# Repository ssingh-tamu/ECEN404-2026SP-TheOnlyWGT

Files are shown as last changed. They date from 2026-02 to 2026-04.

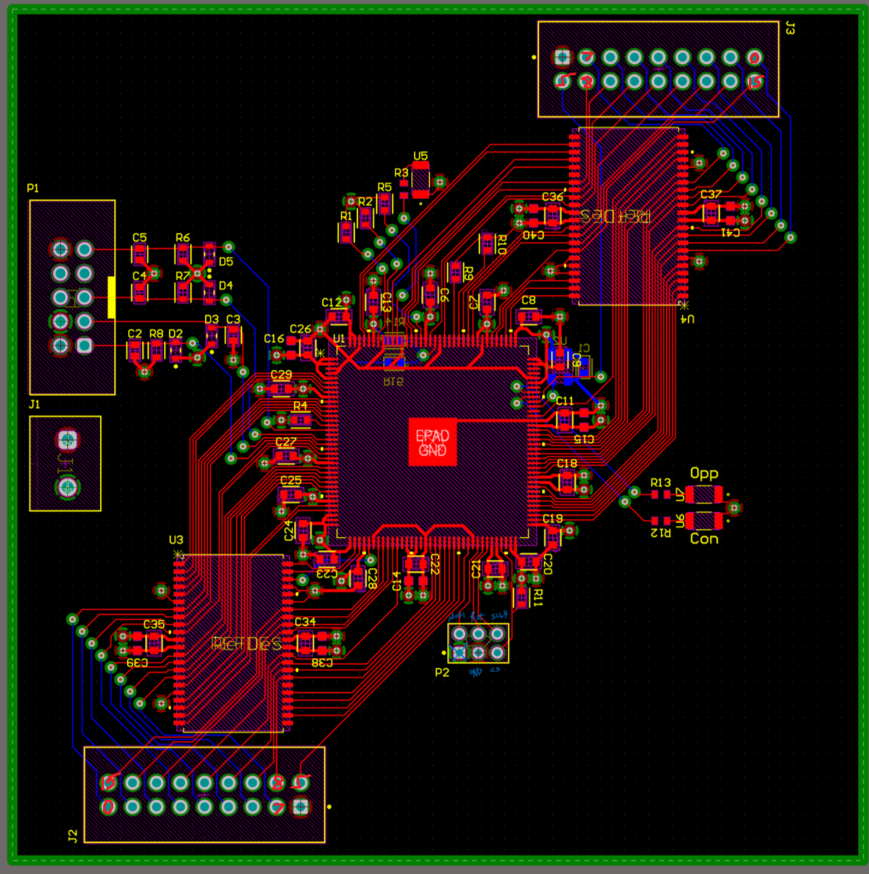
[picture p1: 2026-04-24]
FPGA/fpga pcb pinout.png

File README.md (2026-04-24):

# The-Only-WGT-FinalGIT
ECEN CAPSTONE: 2 Channel Arbritrary Waveform Generating team #25 at TAMU. 

Sponsor:
Dr. John Lusher (johnlusher)

Contents:
Project data, reports, presentations, code, measurements, plans, and results. 

How to use code:
Download code as a zip file and run locally on personal device
Mobile App: Use VScode or other compatible IDE and Arduino IDE to start BLE search

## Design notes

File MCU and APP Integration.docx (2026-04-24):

STANDARD FUNCTIONS- Completed

- BLE peripheral name: ESP32-JOE
- Service UUID (Nordic UART / NUS): 6e400001-b5a3-f393-e0a9-e50e24dcca9e
- App steps (connect):
  - Scan for a BLE device named ESP32-JOE (or advertising the NUS service UUID above)
  - Connect
  - Discover services/characteristics
  - Find these characteristics under the NUS service:
    - RX (WRITE to ESP32): 6e400002-b5a3-f393-e0a9-e50e24dcca9e
    - TX (NOTIFY from ESP32): 6e400003-b5a3-f393-e0a9-e50e24dcca9e

To send a Standard Wave command (STD):

  - Do a GATT Write to the RX characteristic (6e400002-...)
  - Payload is 17 bytes total, little-endian for multi-byte numbers:
- STD packet format (17 bytes):
  - Byte 0: 'S' (0x53)
  - Byte 1: shape (u8)
    - 0 = sine
    - 1 = square
    - 2 = triangle
    - 3 = sinc
  - Bytes 2–5: freq_mHz (u32, little-endian)
    - freq in milli-Hz = Hz * 1000
  - Bytes 6–9: amp_mVpp (u32, little-endian)
    - amplitude in mV peak-to-peak = Vpp * 1000
  - Bytes 10–13: offset_mV (s32, little-endian)
    - DC offset in mV = V * 1000 (signed)
  - Bytes 14–15: phase_deg (s16, little-endian)
    - phase in degrees (signed)
  - Byte 16: channel (u8)
    - 0 = channel A
    - 1 = channel B
- Example values (so they can sanity check):
  - 1 kHz → freq_mHz = 1,000,000
  - 2.0 Vpp → amp_mVpp = 2000
  - +0.5 V offset → offset_mV = 500
  - phase 90° → phase_deg = 90
  - channel A → channel = 0

ARBITRARY FUNCTIONS- SCRAPED

“Interpolation” of points to reduce transmission time.

Here’s a quick write-up you can paste to the app person. It’s written like a mini “protocol spec”.

## ESP32 BLE Connection + Arbitrary Waveform Upload (Protocol)

### 1) BLE service + characteristics

The ESP32 advertises as ESP32-JOE and uses the Nordic UART Service (NUS).

Discover:

- Service UUID: 6e400001-b5a3-f393-e0a9-e50e24dcca9e
- RX (Write) characteristic UUID: 6e400002-b5a3-f393-e0a9-e50e24dcca9e ← app writes packets here
- TX (Notify) characteristic UUID: 6e400003-b5a3-f393-e0a9-e50e24dcca9e (optional; not required for upload)

Connection steps:

1. Scan for ESP32-JOE
2. Connect
3. Discover NUS service
4. Write all commands to the RX characteristic

### 2) Arbitrary waveform upload overview

Arbitrary waveform upload is 3 phases:

1. META: start upload + set channel + set frequency
2. DATA: stream 16-bit samples in chunks(Edit this so app sends all 64k points)
3. END: commit (only succeeds if exactly 1024 samples received)

Total samples required: 1024 (exactly)

All multi-byte integers are Little Endian (LE).

### 3) Packets

#### A) META packet (start new ARB upload)

Format:
'A' + channel(1 byte) + freq_mHz(u32 LE)

- Byte 0: ASCII 'A' = 0x41
- Byte 1: channel:
  - 0 = Channel A
  - 1 = Channel B
- Bytes 2–5: freq_mHz as uint32 LE
  - Frequency is in milli-Hz (Hz * 1000)

Example: Channel A, 1000 Hz
freq_mHz = 1,000,000
Payload: [0x41, 0x00, 0x40, 0x42, 0x0F, 0x00]

Sending META resets/clears the ARB buffer on the MCU.

#### B) DATA packet (send samples)

Format:
'D' + count(u16 LE) + samples[count] (each sample u16 LE)

- Byte 0: ASCII 'D' = 0x44
- Bytes 1–2: count = number of samples in this packet (uint16 LE)
- Remaining bytes: count samples, each a uint16 LE DAC code

Repeat DATA packets until the MCU has received 1024 total samples.

#### C) END packet (commit)

Format:
'Z'

- Single byte: ASCII 'Z' = 0x5A

Commit rules:

- MCU only commits if META was received and exactly 1024 samples have been received total.
- If not 1024, it rejects the upload.

### 4) Sample encoding (what the 16-bit numbers mean)

Each sample is a raw uint16 DAC code: 0 … 65535.

If your app generates values in volts and the hardware range is ±5 V, map like this (clamp to range):

- code = round((v + 5.0) * (65535 / 10.0))
- v = −5.0 → 0
- v = +5.0 → 65535

(If the app already generates 0..65535 codes, send directly.)

### 5) BLE payload sizing / chunk size

DATA packet size is: 3 + 2*count bytes.

Pick count so the whole DATA packet fits in the BLE write payload (depends on MTU).

- If MTU is default (~20 payload bytes), max count ≈ 8 samples per packet.
- If MTU is negotiated larger (recommended), you can send bigger chunks (ex: 60 samples → 123 bytes).

Recommendation:

- Request a higher MTU if supported and stream DATA packets sequentially (write-with-response preferred for reliability).

### 6) Minimal send sequence summary

1. Connect to BLE device ESP32-JOE
2. Write META: 'A' + channel + freq_mHz(LE u32)
3. Send DATA packets until 1024 samples total are sent
4. Write END: 'Z'

# Arbitrary Waveform Upload

### BLE Packet Flow – Explained (with Real Example)

This document explains why multiple BLE packets are sent when uploading an arbitrary waveform and what each packet means on the MCU side.

## Overview

When sending an arbitrary waveform to the MCU:

- The waveform always contains exactly 1024 samples
- Samples are sent in chunks to fit BLE packet size limits
- The upload happens in three phases:
  1. META (start upload)
  2. DATA (send waveform samples)
  3. END (commit waveform)

## Packet Types Summary

Packet | Byte | Purpose
META | 'A' (0x41) | Start ARB upload, set channel & frequency
DATA | 'D' (0x44) | Send waveform samples
END | 'Z' (0x5A) | Commit waveform (only if 1024 samples received)

Any packet that is not the standard 17-byte AWG packet ('S') is logged by the MCU as NON-STANDARD PACKET — this is expected.

## Real Example From MCU Log

RX write [123 bytes]

RX write [11 bytes]

RX write [1 bytes]

This is correct and expected behavior.

## 1️⃣ First Packet – DATA (123 bytes)

44 3c 00 ...

### What it means:

- 0x44 → 'D' = DATA packet
- 0x3c 0x00 → 60 samples (little-endian)
- Remaining bytes → 60 × 2 = 120 bytes of sample data

### Why 123 bytes total?

1 byte → 'D'

2 bytes → sample count

120 bytes → waveform samples

123 bytes total

✔ This is the main waveform chunk
✔ Size chosen to fit BLE MTU safely

## 2️⃣ Second Packet – DATA (11 bytes)

44 04 00 45 67 45 67 45 67 45 67

### What it means:

- 'D' → DATA packet
- 0x04 0x00 → 4 samples
- 4 × 2 = 8 bytes of data

### Why only 4 samples?

1024 total samples

− 60 × 17 packets = 1020 samples

4 samples remaining

✔ This packet sends the final remainder

## 3️⃣ Final Packet – END (1 byte)

5a

### What it means:

- 0x5A → 'Z' = END / COMMIT packet

### What the MCU does here:

- Checks:
  - META packet was received
  - Exactly 1024 samples were received
- If valid → waveform is committed
- If not → upload is rejected

✔ This byte is always exactly 0x5A
✔ No payload, no length field

## Why the MCU Prints “NON-STANDARD PACKET”

The MCU firmware distinguishes between:

- Standard AWG packet ('S', 17 bytes)
- Arbitrary waveform packets ('A', 'D', 'Z')

So the log message:

>>> NON-STANDARD PACKET

Simply means:

“This is not the 17-byte AWG packet”

It does not indicate an error.

## Final Packet Flow Summary

Order | Packet | Size | Purpose
1 | 'A' | 6 bytes | Start upload (META)
2 | 'D' | 123 bytes | 60 samples
3 | 'D' | 123 bytes | 60 samples
… | 'D' | 123 bytes | More chunks
n | 'D' | 11 bytes | Final 4 samples
last | 'Z' | 1 byte | Commit waveform

## Key Takeaways

- Multiple DATA packets are required
- Different packet sizes are normal
- The final 0x5A byte is mandatory

ARBITRARY FUNCTIONS- App sends full 64k Packet: (MCU Getting larger memory chip) PSRAM 8MG useable

- Expect transmission time to be longer

## ESP32 BLE Connection + Arbitrary Waveform Upload (Protocol)

### 1) BLE service + characteristics

The ESP32 advertises as ESP32-JOE and uses the Nordic UART Service (NUS).

Discover:

- Service UUID: 6e400001-b5a3-f393-e0a9-e50e24dcca9e
- RX (Write) characteristic UUID: 6e400002-b5a3-f393-e0a9-e50e24dcca9e ← app writes packets here
- TX (Notify) characteristic UUID: 6e400003-b5a3-f393-e0a9-e50e24dcca9e (optional; not required for upload)

Connection steps:

5. Scan for ESP32-JOE
6. Connect
7. Discover NUS service
8. Write all commands to the RX characteristic

### 2) Arbitrary waveform upload overview

Arbitrary waveform upload is 3 phases:

4. META: start upload + set channel + set frequency
5. DATA: stream 16-bit samples in chunks(Edit this so app sends all 64k points)
6. END: commit (only succeeds if exactly 1024 samples received)

Total samples required: 1024 (exactly)

All multi-byte integers are Little Endian (LE).

### 3) Packets

#### A) META packet (start new ARB upload)

Format:
'A' + channel(1 byte) + freq_mHz(u32 LE)

- Byte 0: ASCII 'A' = 0x41
- Byte 1: channel:
  - 0 = Channel A
  - 1 = Channel B
- Bytes 2–5: freq_mHz as uint32 LE
  - Frequency is in milli-Hz (Hz * 1000)

Example: Channel A, 1000 Hz
freq_mHz = 1,000,000
Payload: [0x41, 0x00, 0x40, 0x42, 0x0F, 0x00]

Sending META resets/clears the ARB buffer on the MCU.

#### B) DATA packet (send samples)

Format:
'D' + count(u16 LE) + samples[count] (each sample u16 LE)

- Byte 0: ASCII 'D' = 0x44
- Bytes 1–2: count = number of samples in this packet (uint16 LE)
- Remaining bytes: count samples, each a uint16 LE DAC code

Repeat DATA packets until the MCU has received 1024 total samples.

#### C) END packet (commit)

Format:
'Z'

- Single byte: ASCII 'Z' = 0x5A

Commit rules:

- MCU only commits if META was received and exactly 1024 samples have been received total.
- If not 1024, it rejects the upload.

### 4) Sample encoding (what the 16-bit numbers mean)

Each sample is a raw uint16 DAC code: 0 … 65535.

If your app generates values in volts and the hardware range is ±5 V, map like this (clamp to range):

- code = round((v + 5.0) * (65535 / 10.0))
- v = −5.0 → 0
- v = +5.0 → 65535

(If the app already generates 0..65535 codes, send directly.)

### 5) BLE payload sizing / chunk size

DATA packet size is: 3 + 2*count bytes.

Pick count so the whole DATA packet fits in the BLE write payload (depends on MTU).

- If MTU is default (~20 payload bytes), max count ≈ 8 samples per packet.
- If MTU is negotiated larger (recommended), you can send bigger chunks (ex: 60 samples → 123 bytes).

Recommendation:

- Request a higher MTU if supported and stream DATA packets sequentially (write-with-response preferred for reliability).

### 6) Minimal send sequence summary

5. Connect to BLE device ESP32-JOE
6. Write META: 'A' + channel + freq_mHz(LE u32)
7. Send DATA packets until 1024 samples total are sent
8. Write END: 'Z'

MCU should…

Receive META 'A' with 10 bytes:

- [0]='A'
- [1]=channel
- [2..5]=freqMilliHz (uint32 LE)
- [6..9]=totalSamples (uint32 LE) → 32768

Receive many 'D' packets containing:

- 'D', count (uint16 LE), then count uint16 DAC samples

Stop on 0x5A

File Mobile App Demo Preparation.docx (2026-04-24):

## Mobile App

### 1. Purpose

- The mobile app provides a simple, intuitive way to connect to the AWG and create, edit, and transmit user-defined waveforms.
- Built in Flutter for cross-platform support on iOS, Android, and PC.
- Main goal: give users an easy way to control waveform generation from a mobile device.

### 2. Design Requirements

- Sponsor requirements from the FSR contract:
  - Define offset, frequency, amplitude, waveform type, and channel
  - Maintain a reliable and stable BLE connection
  - Prioritize simplicity, ease of use, adjustability, and include user-safegaurds
- Built-in safeguards:
  - Prevents drawing invalid arbitrary waveforms such as intersecting values, backward traces, or values outside the amplitude range
  - Prevents entering frequency, VPP, or offset values outside allowed limits
  - Detects BLE disconnects and prompts the user to reconnect
  - Only searches for ESP32 BLE devices, making connection faster and clearer

### 3. Connection Screen

- This is the first screen users see.
- The app scans only for ESP32 BLE devices and displays their names for easy selection.
- Users can quickly connect to the AWG through BLE.
- If the connection is lost, the app alerts the user and prompts reconnection.

How it works

- BLE communication is handled through RX/TX between the app and the ESP32.
- This creates a simple wireless link between the mobile device and the AWG controller.

### 4. Standard Waveform Screen

- This screen functions like a traditional signal generator interface.
- Users can configure:
  - Frequency
  - Amplitude
  - Offset
  - Waveform type
  - Channel

How it works

- The app sends a parameterized string in a predefined format to the MCU.
- The MCU uses those parameters to select and generate standard waveforms from stored LUTs.

### 5. Drawable Arbitrary Waveform Screen

- This screen allows users to draw their own custom waveform on a canvas.
- The interface is designed to keep the drawing valid and within system limits.
- Users cannot draw non-functions or values outside the allowed amplitude range.

### 6. Editing Screen

- After drawing, users can refine the waveform before sending it.
- Users can apply edits such as:
  - Frequency
  - Channel
  - Offset
- This gives more control before transmitting the final waveform.

How it works

- The drawn waveform is converted into 64k discrete values.
- Those values are sent to the MCU along with the selected frequency, channel, and offset settings.
- The MCU then generates a unique LUT for that arbitrary waveform.

Enclosure

1. Purpose

- The enclosure houses and protects the system components while keeping the design compact, lightweight, and easy to service.
- It was designed to support the PCB securely while still allowing access for adjustments and future upgrades.

### 2. Design Requirements

- Required weight: less than 5.5 lbs
  - Final weight: 501 grams without the lid
- Required footprint: less than 12 x 8 x 10 inches
  - Final dimensions with lid: 8 x 8 x 5 inches

### 3. Structural Features

- The enclosure is self-supporting
- Uses Velcro for easy PCB removal and reinstallation
- Includes two open rail slots for interior PCB adjustability
- Extra interior space allows for:
  - wire routing
  - component adjustments
  - future upgrades if needed

### 4. Manufacturing and Material Choices

- The box was 3D printed in PLA and CADed using SOLIDWORKS
- Reduced interior infill
  - minimize weight
  - reduce material cost
  - maintain sufficient structural support

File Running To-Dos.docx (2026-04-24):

To Dos:

- ~~Measure all subsystems PCBs~~
- ~~Verify Standard Waveforms send to MCU subsystem correctly (17 bytes completely decodeable)~~
- ~~Re-added kHz button to standard waveforms page~~
  - ~~Kept in Hz just increased range to 100000 Hz~~
- ~~Start CAD design on enclosure based on measurements~~
- ~~Redesign Arbitrary waveforms packet sending protocol - by next lab~~
- ~~Remove Gain (Already on +-5 Scale)~~
- ~~Keep Offset scale~~
- ~~Add Frequency indicator~~
- ~~Add Channel dropdown (Either Channel A or B)~~

Before Next Lab Complete The following

- ~~RN sending 32k samples and needs to send 64K samples~~
- ~~Send 128 kBytes~~
- ~~Remove phase offset slider~~
- Redo Enclosure dimensions
- Print Enclosure + Test Fit

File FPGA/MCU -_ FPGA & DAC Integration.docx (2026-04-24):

Need to set 2 values:

- Frequency Tuning word
  - 100/101 + 0x00000000
- Reset Value
  - 010/011 + 0x0000 + 0xXXXX

Max DAC Speed: 2 Megasamples / second

FPGA Clock Speed: 100 MHz

Digital Direct Synthesis

Frequency Tuning Word Equation: Fout=M*100E6 / 2^32

- M = binary tuning word
- Fout = Output frequency * Samples per period

Example:

- 10 Hz Wave
  - Fout = 10 Hz * 2^16 samples = 0.65536 MHz
  - Frequency tuning word: 0x01AD7F29
  - Reset value: 0xFFFF
- 15 Hz Wave
  - Fout = 15 Hz * 2^16 samples = 0.98304 MHz
  - Frequency tuning word: 0x02843EBE
  - Reset value: 0xFFFF
- 1 MHz / 2^16 = 15.2587891 Hz
  - Maximum frequency where whole lookup table can be used, assuming 1 MHz is maximum frequency
- 16 Hz Wave
  - Fout = 16 Hz * 2^16 samples = 1.048576 MHz
    - Higher than maximum frequency, set Fout at max frequency of 1 MHz
  - Frequency tuning word = (1MHz)/(100 MHz)( 2^32 ) = 0x028F5C29
  - Samples = 1 MHz / 16 Hz = 62500 = 0xF424
- 100 kHz Wave
  - Frequency tuning word = 0x028F5C29
  - Samples = 1 MHz / 100 kHz = 10 = 0x000A

TODO:

- Arbitrary waveform integration
- Don’t reprogram memory if only changing the frequency

Pinout to MCU

(towards FPGA)

MOSI (MCU -> FPGA) | Reset (Unused MISO) | SPI Clock (SCLK)
~~VCC~~ (Unused) | GND | Chip Select (CS)

(outside of board)

Pinout to DAC

(towards FPGA)

15 | 14 | 13 | 12 | 11 | 10 | 9 | 8 | Clock
0 | 1 | 2 | 3 | 4 | 5 | 6 | 7 | GND

(outside of board)

Pinout on DAC Board

(outside of board)

11 | 12 | 13 | 14 | 15 | Clk | | 5V | | 0 | 1 | 2 | 3 | 3.3V | 4 | 5 | 6 | 7 | 8 | 9 | 10 | Gnd

(towards DAC)

Tables are seen with the top of the table pointing towards the FPGA.

The bottom of the DAC table is towards the edge of the board. Applies to both 18 pin headers.

All pins except the VCC on the 6 pin header should be used.

Colors on 18 pin table represent the groupings of wires to the analog board.

TA Email: balamurugan_22@tamu.edu

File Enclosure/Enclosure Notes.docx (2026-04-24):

Board Measurements for Enclosure

FPGA:

L*W*H

3.5’’ x 3.5’’ 0.5’’

Power Board: Has AC to DC converter barrel jack

L*W*H

2 ¾ ‘’ * 3.5’’ *0.5’’

Filter Board:

Contains BNC Jacks

L*WL*H

4 2/8 * 1 ⅝ * 1 ⅛

BNC Jack width

Separation end to end: 2 2/4’’

1cm diameter

MCU Board:

L*W*H

3.5’’ * 1.25 ‘’ 0.75’’’

Wiring Layout:

MCU → FPGA →Filter Board →PowerBoard

3.2.2.1 | Mass | The Arbitrary Waveform Generator shall have a total mass less than or equal to 2.5 kg including the enclosure, PCBs, and connectors | Measure the system with a scale
3.2.2.2 | Volume Envelope | The volume envelope of the AWG shall not exceed 12 in. (length) × 8 in. (width) × 10 in. (height) | Measure the system with a ruler
3.2.2.3 | Mounting (External) | The AWG enclosure shall be self-supporting for tabletop use, with optional screw holes or slots to allow attachment to a larger test fixture if needed | Place the assembled enclosure on a flat surface and verifying stable tabletop support and mechanical compatibility with optional mounting holes

1. Make Longer Wire harnesses for FPGA to filter board

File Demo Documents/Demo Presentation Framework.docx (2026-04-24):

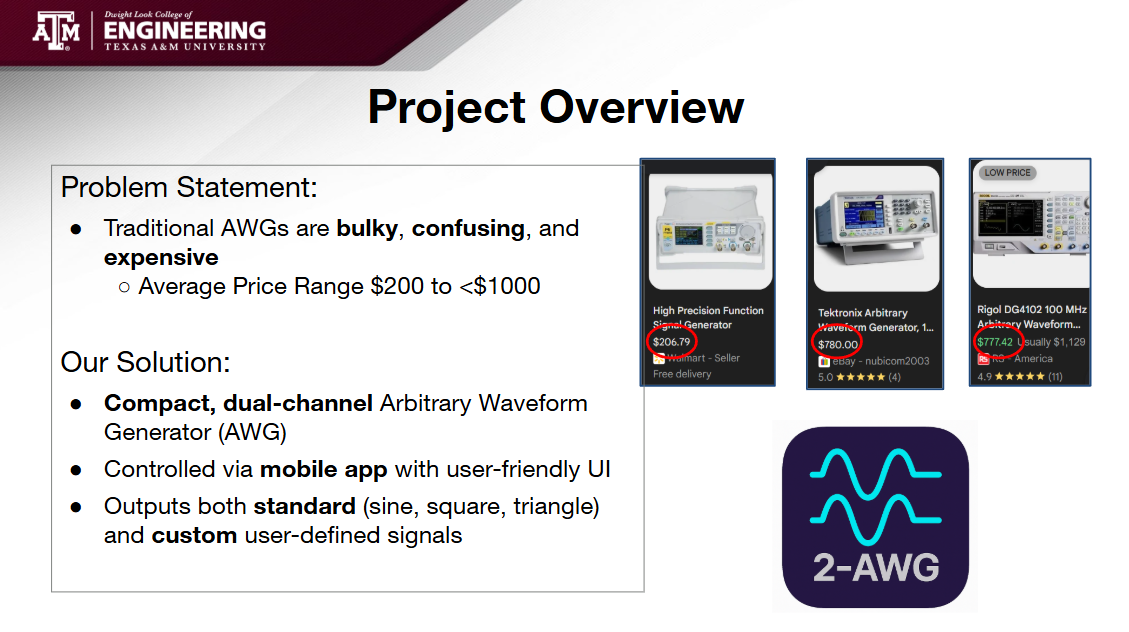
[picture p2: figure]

1minute above

Talk about role/validated line items in project

1. Mobile- 1 min
2. MCU- 1 min
3. FPGA- 1 min
4. Filter/Power- 1.5-2 min

Full System Demo- Rest is Demonstration

- Frequency
- Amplitude
- Offset
- All standard waveforms
- All Arbitrary waveforms

Q/A- leftover

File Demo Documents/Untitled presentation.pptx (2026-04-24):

## Mobile App/Enclosure

CAPSTONE DEMO

Serene Singh

## Purpose of the Mobile App Company Name

Provide an easy way to connect, create, and transmit user-defined waveforms.
- Built using Flutter which allows cross platform support on IOS, Android, and PC

## Year/Quarter/Month Simple User Experience

Step 1

Connect
Connect via BLE

Step 2

Configure
Focus on key milestones, meetings and events.

Step 4

Send
For example, mention the project kickoff, the first delivery, go-live date, etc.

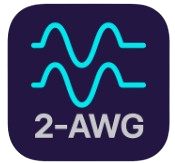
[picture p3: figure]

## Company Name A headline about the challenges you’re facing Year/Quarter/Month

Problem 1
Describe a problem or challenge currently affecting your market, your customers, or your company.

Problem 2
Describe a problem or challenge currently affecting your market, your customers, or your company.

## Motivations Tech skills Favorite brands Company Name Persona name “Quote the persona on their needs and wants. This can be a fictional line or an excerpt from a user interview.” Goals Year/Quarter/Month

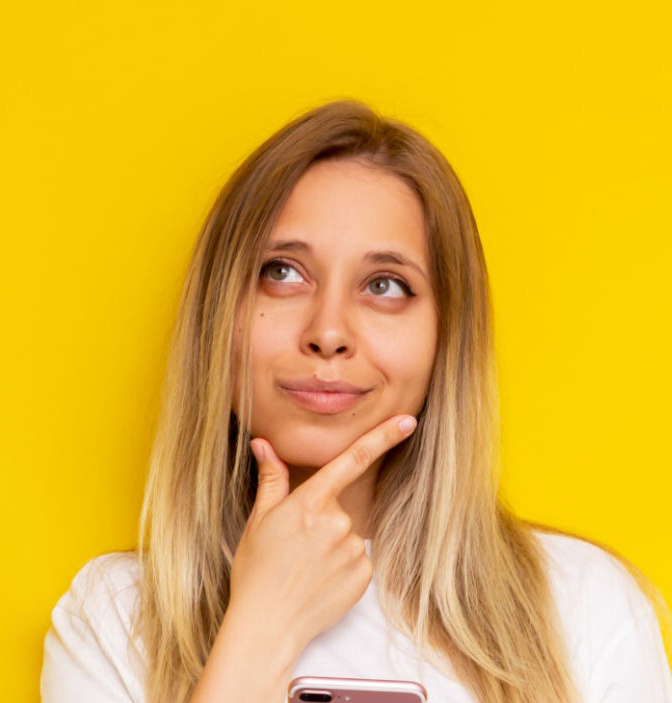
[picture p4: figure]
A woman thinks looking away from the camera while standing in front of a yellow background

Think about a hypothetical user or customer (a persona) who represents an audience segment. Introduce your persona, who they are and where they come from.
The individual might be fictional, but the insights should be derived from your audience research.

Driver 1

Driver 2

Driver 3

Device 1

App 1

Device 2

App 2

Role

Age

Profession

1. What do they want to achieve?
2. What do they care about?
3. What solutions are they looking for?

Location

Motivation

Add logo

Add logo

Education

## Company Name Year/Quarter/Month Introduce your persona or target audience

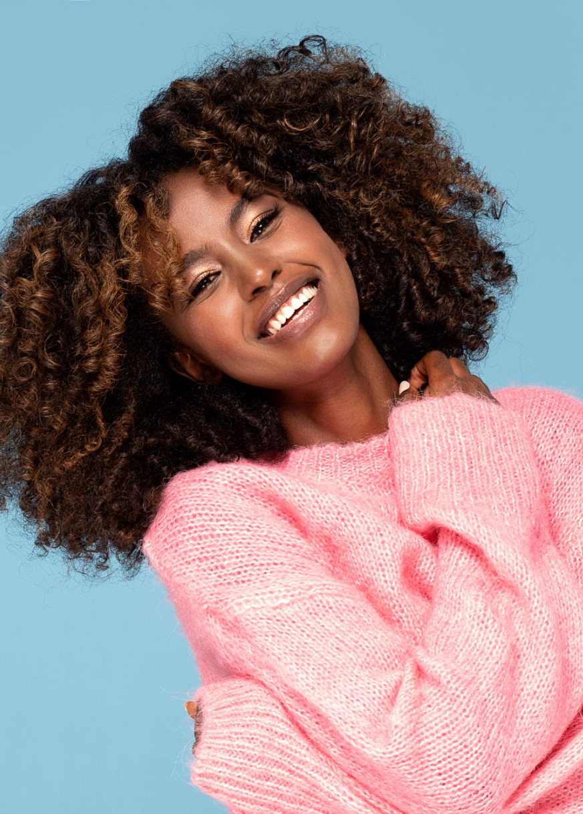
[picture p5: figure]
A woman in pink sweater smiles at camera

Needs and motivations
What does your persona want, and what do they care about?
Pain points
What challenges does your persona face? What are their concerns?
How we can help
Describe how your product meets the needs of your persona and addresses their pain points.

Persona name
Introduce a persona, or fictional character, that represents your target audience.
Age:
Profession:

## Year/Quarter/Month Company Name Communication objectives Business objectives How we’ll measure the success of this project Marketing objectives

A brief description of the key performance indicator (KPI)
Goal: 00%

A brief description of the key performance indicator (KPI)
Goal: 00%

A brief description of the key performance indicator (KPI)
Goal: 00%

A brief description of the key performance indicator (KPI)
Goal: 00%

A brief description of the key performance indicator (KPI)
Goal: 00%

A brief description of the key performance indicator (KPI)
Goal: 00%

## Communication objectives Year/Quarter/Month Company Name 1 2 3 4

Write a few words about your communication goals for this project.

Objective title

Communication goals might include: increasing brand awareness, improving how your teams work together, or getting more consistent feedback from stakeholders.

Objective title

Communication goals might include: increasing brand awareness, improving how your teams work together, or getting more consistent feedback from stakeholders.

Objective title

Communication goals might include: increasing brand awareness, improving how your teams work together, or getting more consistent feedback from stakeholders.

Objective title

Use design elements to highlight key objectives or final outcomes. This will draw your audience’s eye towards the objective.

## Year/Quarter/Month Objective title Objective title Objective title Objective title Company Name Business objectives 1 2 3 4

Write a few words about your business goals for this project.

Business goals might include: driving sales growth, reducing costs, boosting productivity, or streamlining internal processes.

Business goals might include: driving sales growth, reducing costs, boosting productivity, or streamlining internal processes.

Business goals might include: driving sales growth, reducing costs, boosting productivity, or streamlining internal processes.

Business goals might include: driving sales growth, reducing costs, boosting productivity, or streamlining internal processes.

## Year/Quarter/Month Company Name Marketing objectives

Write a few words about your marketing goals for this project.

1

Objective title

Marketing goals might include: reaching new audiences, generating new leads and sales, or strengthening existing customer relationships.

2

Objective title

Marketing goals might include: reaching new audiences, generating new leads and sales, or strengthening existing customer relationships.

3

Objective title

Marketing goals might include: reaching new audiences, generating new leads and sales, or strengthening existing customer relationships.

4

Objective title

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

## Company Name Objectives Phase 1 Phase 2 Phase 3 Activities Deliverables Project roadmap Year/Quarter/Month

Use this slide to map out the steps in more detail. State the main objective for each phase. Think about what needs to be achieved.

Use this slide to map out the steps in more detail. State the main objective for each phase. Think about what needs to be achieved.

Use this slide to map out the steps in more detail. State the main objective for each phase. Think about what needs to be achieved.

- List key tasks
- Be specific and add as many as you need

- List key tasks
- Be specific and add as many as you need

- List key tasks
- Be specific and add as many as you need

- List final outcomes
- These could be documents, prototypes, or reports

- List final outcomes
- These could be documents, prototypes, or reports

- List final outcomes
- These could be documents, prototypes, or reports

## Objectives Phase 2 Project roadmap Phase 1 Phase 3 Activities Deliverables Company Name Year/Quarter/Month

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

- List key tasks
- Be specific and add as many as you need

- List key tasks
- Be specific and add as many as you need

- List key tasks
- Be specific and add as many as you need

- List final outcomes
- These could be documents, prototypes, or reports

- List final outcomes
- These could be documents, prototypes, or reports

- List final outcomes
- These could be documents, prototypes, or reports

Objectives Phase 2 Activities Deliverables Project roadmap Phase 1 Phase 3 Use this slide to map out the steps in more detail. State the main objective for each phase. Think about what needs to be achieved. Use this slide to map out the steps in more detail. State the main objective for each phase. Think about what needs to be achieved. Use this slide to map out the steps in more detail. State the main objective for each phase. Think about what needs to be achieved. List final outcomes These could be documents, prototypes, or reports Year/Quarter/Month Company Name List key tasks Be specific and add as many as you need List key tasks Be specific and add as many as you need List key tasks Be specific and add as many as you need List final outcomes These could be documents, prototypes, or reports List final outcomes These could be documents, prototypes, or reports

Contact list Briefing Meeting minutes Concept deck Comms plan Image library Brand assets Style guides Case studies White paper Other files Other files Other files Other files Other files Other files Full Name Title Email Full Name Title Email Full Name Title Email Links to key files and documents Company Name Resources Year/Quarter/Month

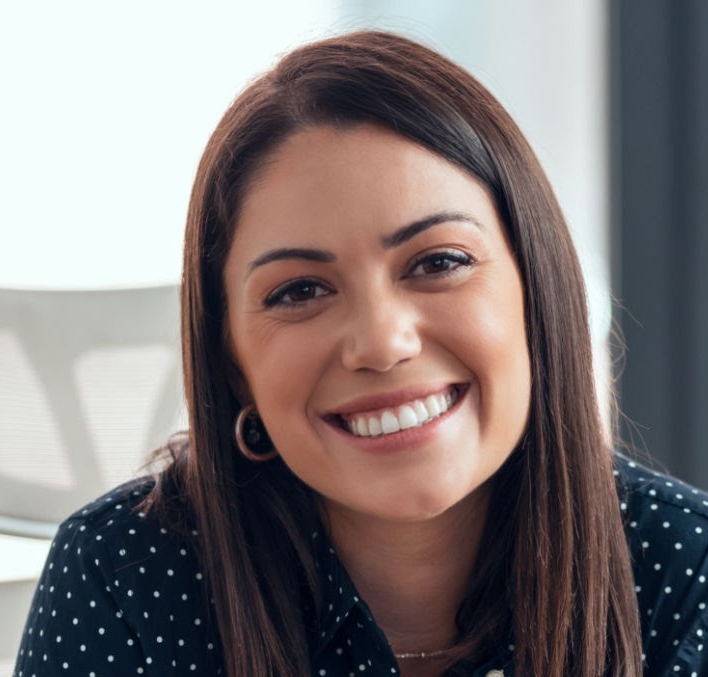
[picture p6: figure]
Smiling business woman working with laptop while looking at camera in modern startup office
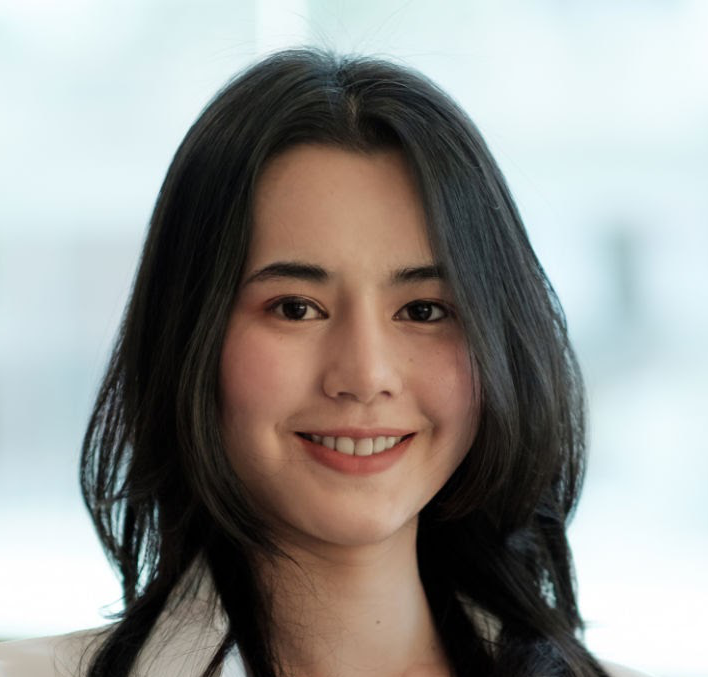
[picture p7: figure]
Portrait of smiling business woman with suit working in office
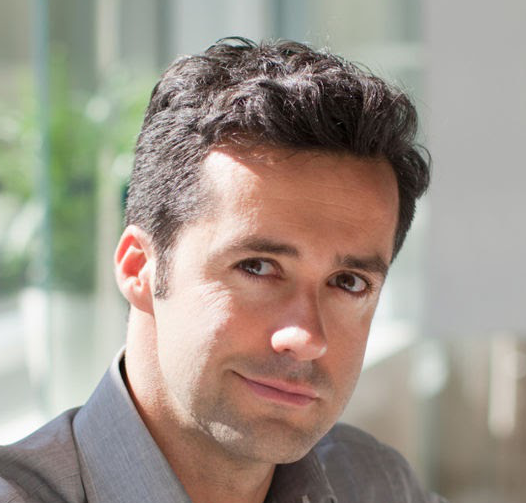
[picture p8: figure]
Businessman using computer in office

## Year/Quarter/Month Company Name RACI matrix project management

Name 1

Name 2

Name 3

Name 4

Project stage 1

R

A

I

C

Project stage 2

R

A

I

C

Project stage 3

R

I

A

C

Project stage 4

Project stage 5

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
Responsible

Accountable

Consulted

Informed

## Company Name Year/Quarter/Month Roadmap

START DATE - END DATE

START DATE - END DATE

START DATE - END DATE

Month 1

Month 2

Month 3

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
Market research

START DATE - END DATE

Specifications

Planning

START DATE - END DATE

Design

Development

START DATE - END DATE

Training

START DATE - END DATE

Assessment

START DATE - END DATE

Documentation

Milestones

## Year/Quarter/Month Company Name Next steps

Step 3

Final Step

Date

Duplicate this slide if you need more steps.

Step 1

Step 2

Project start date

Date

Describe an upcoming phase in the project.

Date

Steps can include further deliverables, team check-ins, etc.

Date

Extensions of the current project, client meetings, etc.

## Year/Quarter/Month Company Name Name of step 1 DATE Name of step 2 DATE Name of step 3 DATE Next steps

We’re here!

Describe the current phase of this project.

Describe an upcoming step, such as further deliverables, check-ins, extensions of the current project, etc.

Add as many steps as you want. Duplicate this slide if you need more.

## Any questions? Ask away! Company Name Year/Quarter/Month

Let's discuss any doubts or concerns.
If something comes up later, contact name@example.com

## Thank you

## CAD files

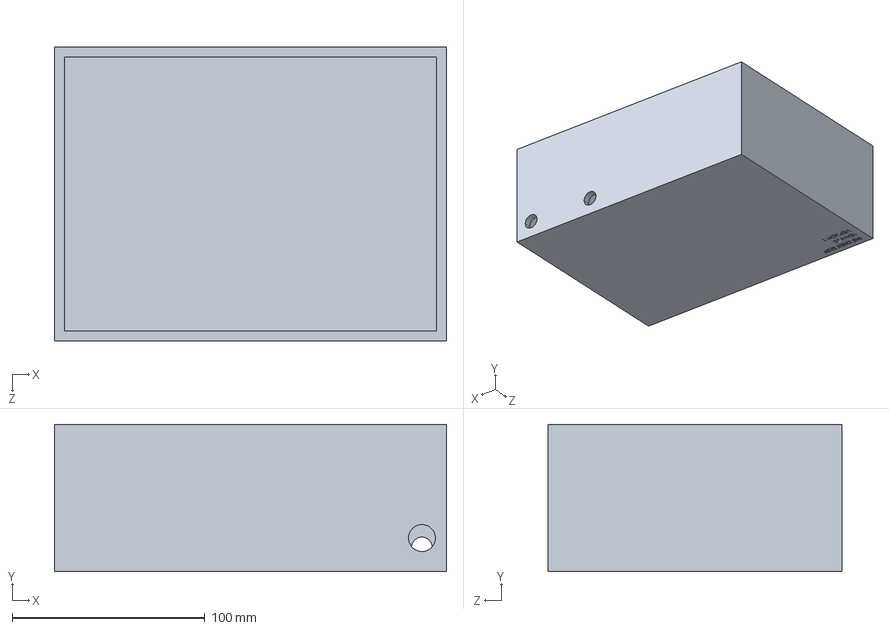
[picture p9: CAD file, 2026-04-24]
Enclosure/Enclosure.STEP
203.2 x 76.2 x 152.4 mm

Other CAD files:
Enclosure/Enclosure.SLDPRT

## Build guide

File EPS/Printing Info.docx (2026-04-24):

https://www.officedepot.com/vendor/vendorRouter.do?id=818654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

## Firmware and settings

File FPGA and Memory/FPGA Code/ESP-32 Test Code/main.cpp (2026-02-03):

#include <Arduino.h>
#include <string>
#include <bitset>
#include <sstream>
#include <cmath>
#include <iomanip>

using namespace std;

void sendFrame(string); // final remove

// FPGA SPI communication functions

void sendBits(int, int);
void setMemory(bool, int, int);
void setReset(bool, int);
void setTuningWord(bool, int);
void run();

// Waveform creation functions

void createSin(bool, int, int, int);
void createSnc(bool, int, int, int);
void createSaw(bool, int); // final remove
void createTri(bool, int, int, int);
void createSqu(bool, int, int, int);

// Main function to set all parameters and create waveform

void setAll(int, int, int, int, bool);

// MCU pin definitions

#define mosi 10
#define rstn 11
#define sclk 12
#define cs_n 13

// sends 35 bit frame to FPGA with SPI
// - frame must be 9 hex characters
// - first hex character must be [0, 7]
void sendFrame(string frame) {

  //decode hex
  ostringstream binaryStream;

  unsigned int firstValue = stoul(frame.substr(0, 1), nullptr, 16);
  bitset<4> firstBits(firstValue);
  binaryStream << firstBits.to_string().substr(1);
  
  for (size_t i = 1; i < frame.size(); ++i) {
    unsigned int value = stoul(frame.substr(i, 1), nullptr, 16);
    bitset<4> bits(value);
    binaryStream << bits.to_string();
  }

  string bframe = binaryStream.str();

  //set pins
  digitalWrite(cs_n, LOW);

  for (char b : bframe) {

    if (b == '0') 
      digitalWrite(mosi, LOW);
    else 
      digitalWrite(mosi, HIGH);

    digitalWrite(sclk, HIGH);
    delayMicroseconds(10);
    digitalWrite(sclk, LOW);
    delayMicroseconds(10);

  }

  digitalWrite(cs_n, HIGH);
  delayMicroseconds(20);

}

// sends number to FPGA via SPI
// - num is a number in decimal
// - len is number of bits (3, 16, or 32)
// - should only be called by set memory, reset, and tuning word functions
void sendBits(int len, int num) {
  for (int i = len-1; i >= 0; i--) {
    if (num >= (1 << i)) {
      num -= (1 << i);
      digitalWrite(mosi, HIGH);
    } else {
      digitalWrite(mosi, LOW);
    }
    digitalWrite(sclk, HIGH);
    delayMicroseconds(1);
    digitalWrite(sclk, LOW);
    delayMicroseconds(1);
  }
}

void setMemory(bool channel, int address, int value) {
  digitalWrite(cs_n, LOW);
  sendBits(3, channel ? 1 : 0);
  sendBits(16, address);
  sendBits(16, value);
  digitalWrite(cs_n, HIGH);
  // delayMicroseconds(5);
}

void setReset(bool channel, int reset) {
  digitalWrite(cs_n, LOW);
  sendBits(3, channel ? 3 : 2);
  sendBits(16, reset);
  sendBits(16, 0);
  digitalWrite(cs_n, HIGH);
  // delayMicroseconds(5);
}

void setTuningWord(bool channel, int tuningWord) {
  digitalWrite(cs_n, LOW);
  sendBits(3, channel ? 5 : 4);
  sendBits(16, tuningWord >> 16);
  sendBits(16, tuningWord % (1 << 16));
  digitalWrite(cs_n, HIGH);
  // delayMicroseconds(5);
}

void run() {
  digitalWrite(cs_n, LOW);
  sendBits(3, 7);
  sendBits(16, 0);
  sendBits(16, 0);
  digitalWrite(cs_n, HIGH);
  // delayMicroseconds(10);
}

// creates sin wave by writing amplitude values to memory values [0, width)
// - SRAM0 - channel = false, SRAM1 - channel = true
// - width must be between [1, 65536]
void createSin(bool channel, int width, int amplitude, int offset) {
  if (width > 65536) return;

  double inc = 2*M_PI/width;
  for (int i = 0; i < width; i++) {
    // int dec = (sin(inc*i)*amplitude+offset*2+10000)*65535/20000;
    int dec = (sin(inc*i)*0.5+0.5)*65535;
    if (dec > 65535) dec = 65535;
    else if (dec < 0) dec = 0;

    setMemory(channel, i, dec);
  }
}

// creates sinc wave by writing amplitude values to memory values [0, width)
// - SRAM0 - channel = false, SRAM1 - channel = true
// - width must be between [1, 65536]
void createSnc(bool channel, int width, int amplitude, int offset) {
  if (width > 65536) return;

  double inc = 14.06619*2/width;
  for (int i = 0; i < width; i++) {
    int dec = (sin(inc*i-14.06619)*amplitude/(inc*i-14.06619)+offset*2+10000)*65535/20000;
    if (dec > 65535) dec = 65535;
    else if (dec < 0) dec = 0;

    setMemory(channel, i, dec);
  }
}

// creates saw tooth wave by writing amplitude values to memory values [0, width)
// - SRAM0 - channel = false, SRAM1 - channel = true
// - width must be between [1, 65536]
void createSaw(bool channel, int width) {
  if (width > 65536) return;
  
  for (int i = 0; i < width; i++) {
    int dec = i*65535/(width-1);
    setMemory(channel, i, dec);
  }
}

// creates triangle wave by writing amplitude values to memory values [0, width)
// - SRAM0 - channel = false, SRAM1 - channel = true
// - width must be between [1, 65536]
void createTri(bool channel, int width, int amplitude, int offset) {
  if (width > 65536) return;
  
  setMemory(channel, 0, 32678-3.2678*amplitude+6.5535*offset);
  for (int i = 0; i < width/2; i++) {
    int dec = 2*(i+1)*6.5535*amplitude/width + 32678 - 3.2678*amplitude + 6.5535*offset;
    if (dec > 65535) dec = 65535;
    else if (dec < 0) dec = 0;

    setMemory(channel, i+1, dec);
    setMemory(channel, width-1-i, dec);
  }
}

// creates a square wave
// - SRAM0 - channel = false, SRAM1 - channel = true
void createSqu(bool channel, int frequency, int amplitude, int offset) {
  setReset(channel, 1);

  // int stw = frequency*2*(1 << 31)/100000000000;
  int stw = frequency*0.042949673;
  setTuningWord(channel, stw);
  
  int top = (10000*32768+amplitude*32768+offset*65536)/10000;
  if (top > 65535) top = 65535;
  else if (top < 0) top = 0;  
  int bot = (10000*32768-amplitude*32768+offset*65536)/10000;
  if (bot > 65535) bot = 65535;
  else if (bot < 0) bot = 0;

  setMemory(channel, 0, top);
  setMemory(channel, 1, bot);
}

// takes in data received from app
// - shape:   0 = sine,   1 = square,   2 = triangle,   3 = sinc,   4 = arbitrary
// - frequency (0 to 100000000 mHz),   amplitude (0 to 10000 mV),   offset (-5000 to 5000 mV)
// - channel:   false = Channel0,   true = Channel1
void setAll(int shape, int frequency, int amplitude, int offset, bool channel) {

  // determine high or low frequency
  int width = 0;
  if (frequency <= 15258) { // 15.258 Hz
    // low frequency, variable tuning word

    width = 65535; // Use max width of 2^16
    setReset(channel, 65535);
    // int tw = frequency*(1 << 48)/100000000000;
    int tw = frequency*1407.37488;
    setTuningWord(channel, tw);

  } else {
    // high frequency, variable reset

    width = 1000000000/frequency;
    setReset(channel, width);
    setTuningWord(channel, 21474836); // set tuning word to 1 MHz, 0.01(2^31) = 21474836
  }

  // call function to generate shape
  switch(shape) {
    case 0:
      createSin(channel, width, amplitude, offset);
      break;
    case 1:
      createSqu(channel, frequency, amplitude, offset);
      break;
    case 2:
      createTri(channel, width, amplitude, offset);
      break;
    case 3:
      createSnc(channel, width, amplitude, offset);
      break;
    case 4:
      // arbitrary waveform
      break;
  }

  // start waveform generation
  run();
}

void setup() {

  Serial.begin(115200);
  pinMode(rstn, OUTPUT);
  pinMode(sclk, OUTPUT);
  pinMode(mosi, OUTPUT);
  pinMode(cs_n, OUTPUT);

  digitalWrite(rstn, LOW);
  digitalWrite(sclk, LOW);
  digitalWrite(mosi, LOW);
  digitalWrite(cs_n, LOW);
  delayMicroseconds(20);
  digitalWrite(rstn, HIGH);

  setAll(0, 230*1000, 5*1000, 0*1000, false);
  // delay(5000);
  // setReset(true, 4347);
  // run();
  // delay(5000);
  // setReset(true, 4347/2);
  // run();

  // // 15 -> 240 repeating memory??????
  // // 244 = 4096 = 2^12????
  // // memory transfer at 65k too slow

  // setAll(1, 1000*1000, 10*1000, 0*1000, true);
  // // sqaure works
  // setAll(1, 0.024*1000, 10*1000, 0*1000, true);
  // // works at very low frequency, about 1 cycle every 42 seconds
  // setAll(1, 100000*1000, 0.1*1000, 5*1000, true);
  // // works at very high frequency

  // setAll(2, 1000*1000, 5*1000, 0*1000, true);
  // tri doesn't work at all

  // setAll(3, 1000*1000, 10*1000, -2*1000, true);
  // // sinc works, but equation needs adjustment
  // setAll(3, 10000*1000, 10*1000, -2*1000, true);
  // // works, test higher later
  // setAll(3, 100*1000, 10*1000, -2*1000, true);

  

  // //=// square wave //=//
  // setReset(true, 1);
  // setTuningWord(true, 4095);
  // setMemory(true, 0, 65535);
  // setMemory(true, 1, 0);
  // run();

  // sendFrame("20001FFFF");
  // sendFrame("4000FFFFF");
  // sendFrame("000000000");
  // sendFrame("00001FFFF");

  // sendFrame("30001FFFF");
  // sendFrame("5000FFFFF");
  // sendFrame("100000000");
  // sendFrame("10001FFFF");

  // sendFrame("7FFFFFFFF");

  //=// sin and saw waves //=//
  // sendFrame("500FFFFFF"); // set phase0 to h00FFFFFF
  // sendFrame("303FFFFFF"); // set reset0 to 1023
  // createSin(1, 1024);     // load sin wave into SRAM0
  // // sendFrame("20003FFFF"); // set reset0 to 3
  // // createSaw(0, 4);
  // sendFrame("7FFFFFFFF");

}

void loop() {

  // setAll(0, 1000000, 4000, 1000, 1);
  // delay(2000);
  // setAll(0, 1000000, 8000, 1000, 1);
  // delay(2000);
  // setTuningWord(1, 10737418);
  // run();
  // delay(2000);
  // setTuningWord(1, 42949672);
  // run();
  // delay(2000);

  // setAll(1, 230*1000, 5*1000, 0*1000, true);
  // delay(2000);


}

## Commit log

2026-02-03 switch to binary, fixed tri
    [main.cpp]
2026-04-24 Enclosure 404 documents
    [Enclosure.SLDPRT, Enclosure.STEP]
